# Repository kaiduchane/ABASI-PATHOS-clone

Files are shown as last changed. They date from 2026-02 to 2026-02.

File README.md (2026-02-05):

# ABASI-PATHOS-clone
The Abasi Pathos is a modern high-gain distortion pedal designed by guitarist Tosin Abasi and Horizon Devices. This project is an open-source clone that reverse-engineers the circuit for educational purposes and DIY builders.
This pedal features a three-band active EQ, dual-stage clipping circuit, and tight low-end response designed for modern progressive metal tones. The design uses through-hole components where possible to make it accessible for beginners while maintaining the sonic characteristics of the original.
Key Features:

Adjustable gain structure with asymmetrical clipping
Active 3-band EQ (Bass/Mid/Treble)
High input impedance JFET buffer
True bypass switching
Standard 9V center-negative power

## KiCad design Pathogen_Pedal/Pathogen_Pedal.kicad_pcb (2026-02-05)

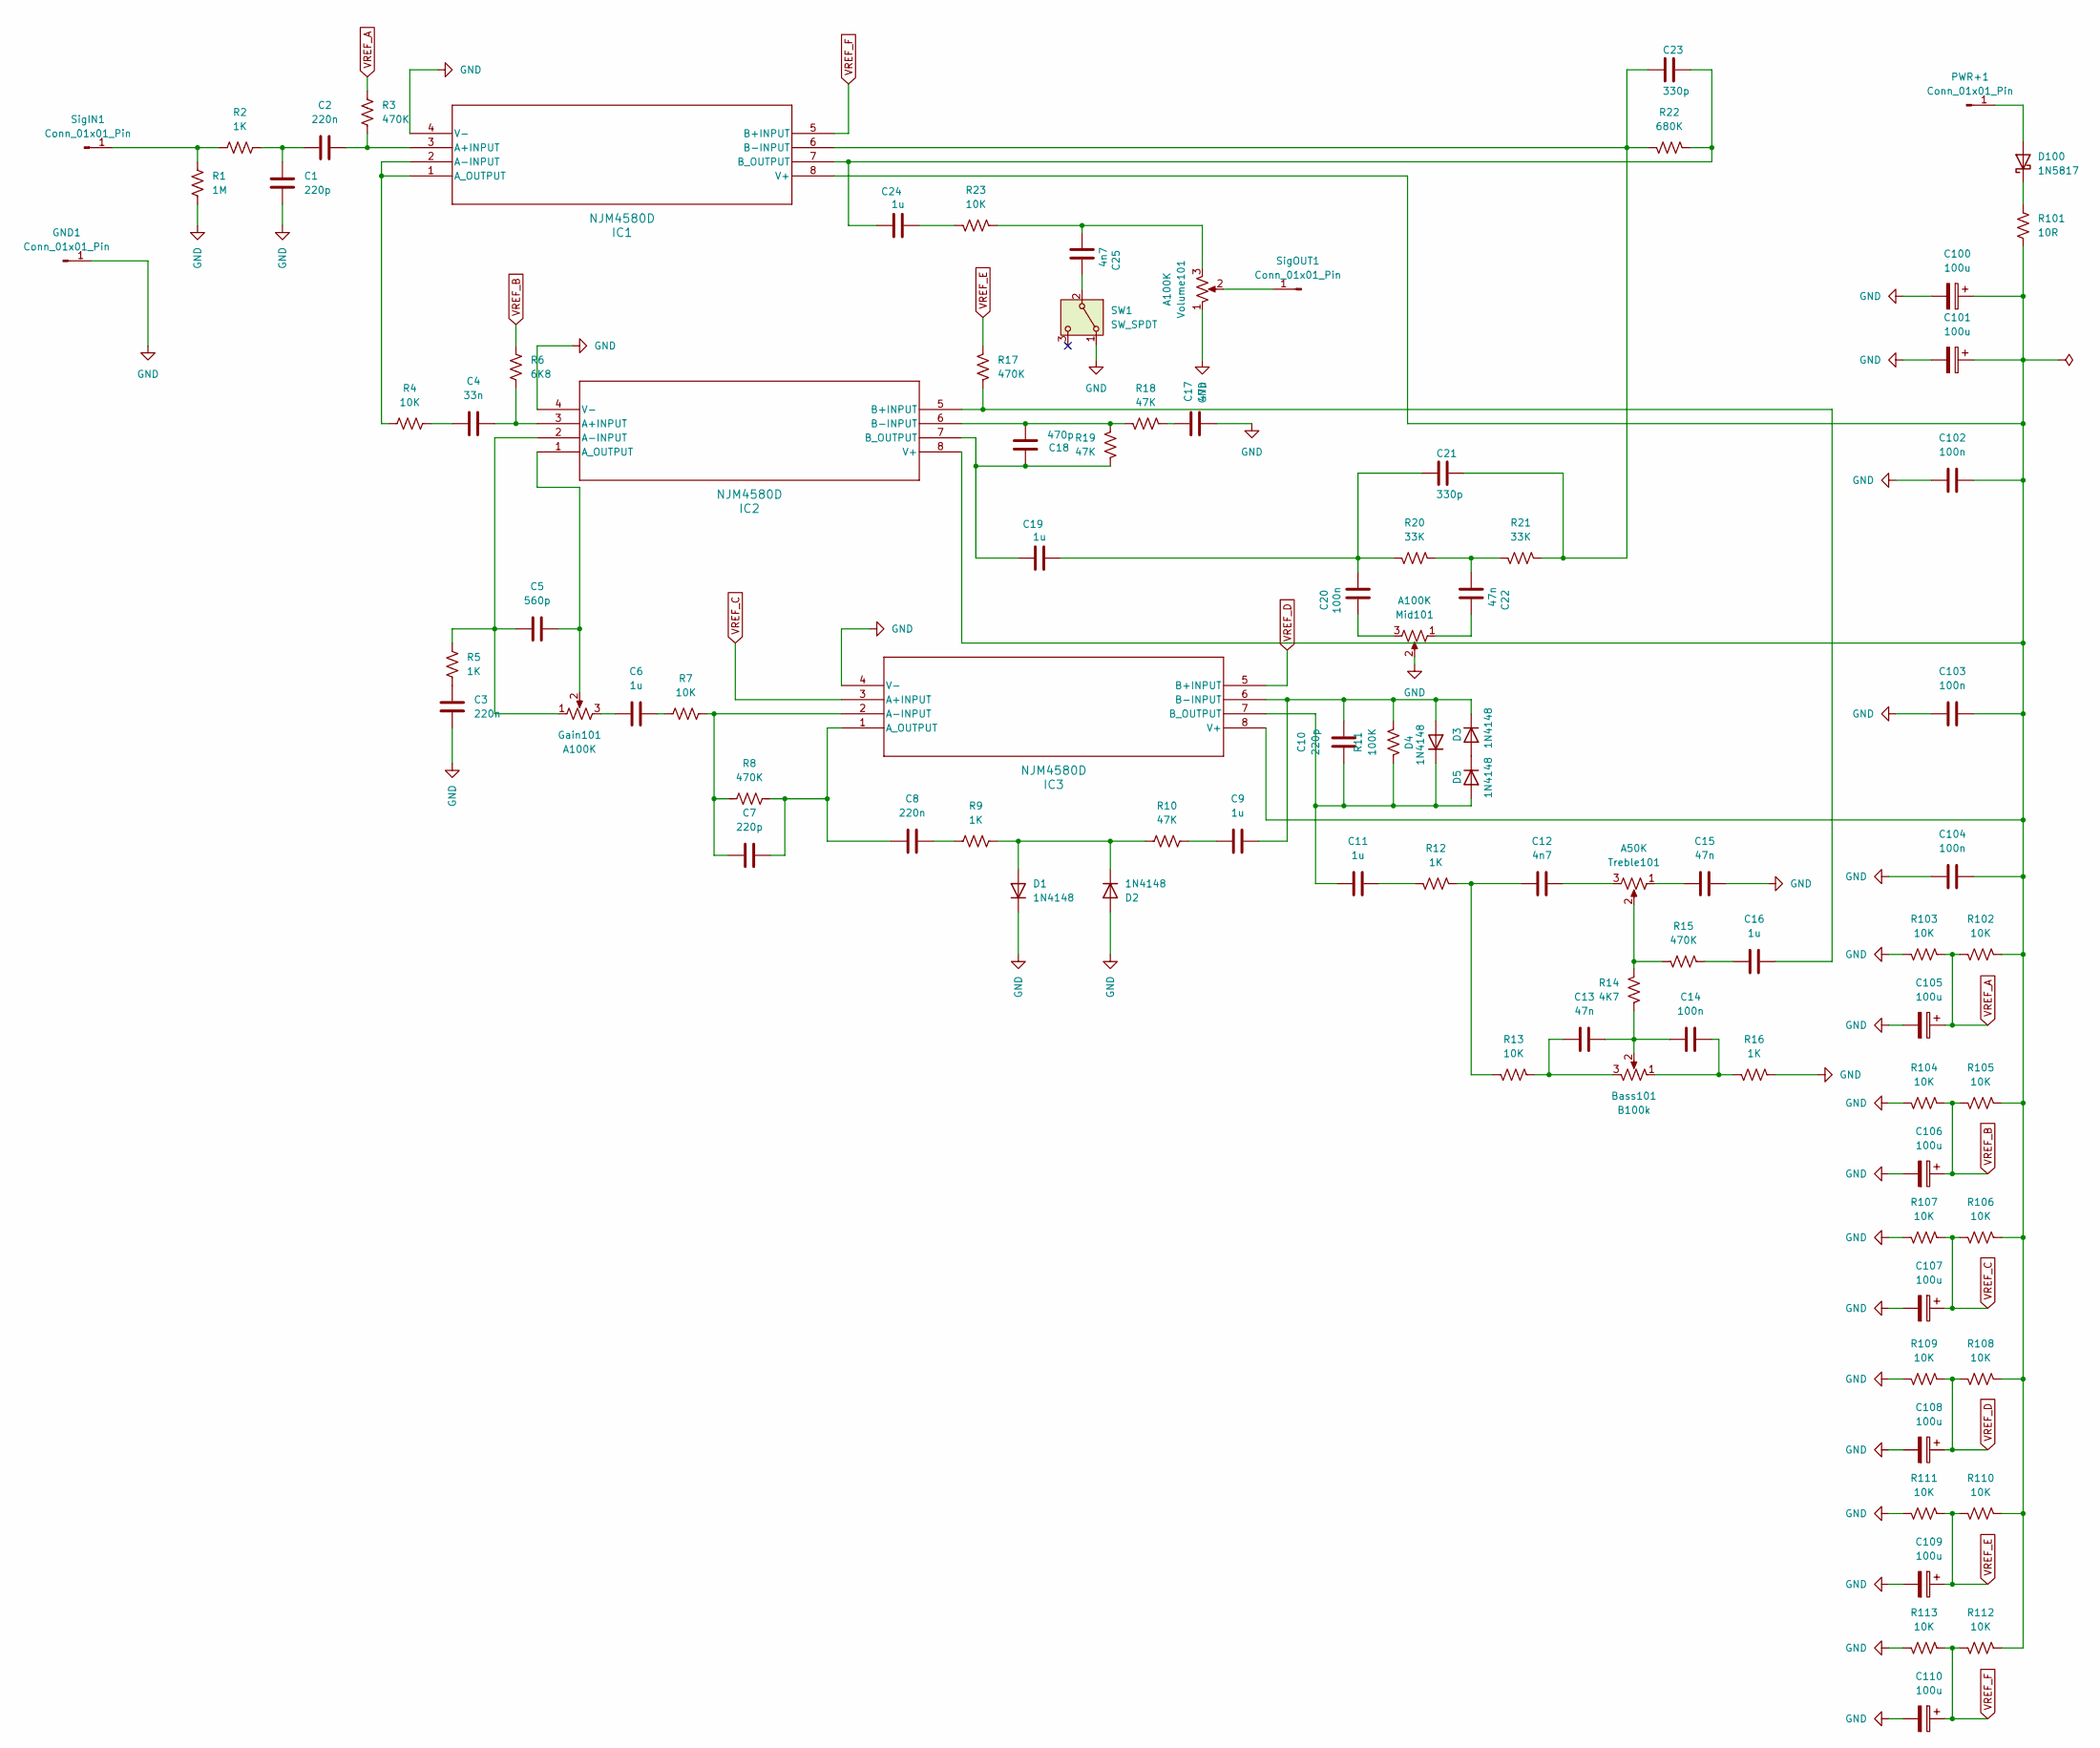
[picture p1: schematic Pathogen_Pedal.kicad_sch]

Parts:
Bass101: B100k; 16MM_PADS.2
C1, C7, C10: 220p; 5mm_10p-180n
C2, C3, C8: 220n; 5mm_1n-300n
C4: 33n; 7.62mm
C5: 560p; 7.62mm
C6, C9, C11, C16, C19, C24: 1u; C_Axial_L12.0mm_D6.5mm_P15.00mm_Horizontal
C12, C25: 4n7; 5mm_1n-300n
C13, C15, C17, C22: 47n; C_Axial_L17.0mm_D6.5mm_P20.00mm_Horizontal
C14, C20, C102, C103, C104: 100n; 5mm_1n-300n
C18: 470p; 5mm_10p-180n
C21, C23: 330p; 7.62mm
C100, C101, C105, C106, C107, C108, C109, C110: 100u; 0503
D1, D2, D3, D4, D5: 1N4148; DO41-2
D100: 1N5817; DO35-3
GND1: Conn_01x01_Pin; PAD3
Gain101: A100K; 16MM_PADS.2
IC1, IC2, IC3: NJM4580D; DIP08
Mid101: A100K; 16MM_PADS.2
PWR+1: Conn_01x01_Pin; PAD3
R1: 1M; 0.3%22.B
R2, R5, R9, R12, R16: 1K; 0.3%22.B
R3, R8, R15, R17: 470K; 0.3%22.B
R4, R7, R13, R23, R102, R103, R104, R105, R106, R107, R108, R109, R110, R111, R112, R113: 10K; 0.5%22
R6: 6K8; 0.3%22.B
R10, R18, R19: 47K; 0.3%22.B
R11: 100K; 0.2%22
R14: 4K7; 0.3%22.B
R20, R21: 33K; 0.4%22
R22: 680K; 0.3%22.B
R101: 10R; 0.3%22.B
SW1: SW_SPDT; SPDT.WIRE
SigIN1: Conn_01x01_Pin; PAD3
SigOUT1: Conn_01x01_Pin; PAD3
Treble101: A50K; 16MM_PADS.2
Volume101: A100K; 16MM_PADS.2

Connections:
GND: C1.2, C3.1, C15.2, C17.1, C100.2, C101.2, C102.1, C103.1, C104.1, C105.2, C106.2, C107.2, C108.2, C109.2, C110.2, D1.1 (K), D2.2 (A), GND1.1, IC1.4 (V-), IC2.4 (V-), IC3.4 (V-), Mid101.2, R1.1, R16.2, R103.1, R104.1, R107.1, R109.1, R111.1, R113.1, SW1.1 (A), Volume101.1
unnamed: Bass101.1, C14.2, R16.1
unnamed: Bass101.2, C13.2, C14.1, R14.1
unnamed: Bass101.3, C13.1, R13.2
unnamed: C1.1, C2.1, R2.1
unnamed: C3.2, R5.1
unnamed: C4.1, R4.2
unnamed: C6.1, R7.2
unnamed: C6.2, Gain101.3
unnamed: C8.1, R9.2
unnamed: C9.2, R10.1
unnamed: C11.2, R12.1
unnamed: C12.1, R12.2, R13.1
unnamed: C12.2, Treble101.3
unnamed: C15.1, Treble101.1
unnamed: C16.1, R15.1
unnamed: C17.2, R18.2
unnamed: C19.1, C20.1, C21.1, R20.1
unnamed: C20.2, Mid101.3
unnamed: C22.1, R20.2, R21.1
unnamed: C22.2, Mid101.1
unnamed: C24.1, R23.1
unnamed: C25.1, R23.2, Volume101.3
unnamed: D1.2 (A), D2.1 (K), R9.1, R10.2
unnamed: D3.2 (A), D5.1 (K)
unnamed: C9.1, C10.1, D3.1 (K), D4.2 (A), IC3.6 (B-INPUT), R11.1
unnamed: C10.2, C11.1, D4.1 (K), D5.2 (A), IC3.7 (B_OUTPUT), R11.2
unnamed 27: D100.2 (A), PWR+1.1; also elsewhere on the board
unnamed 28: D100.1 (K), R101.2; also elsewhere on the board
unnamed: C2.2, IC1.3 (A+INPUT), R3.2
unnamed: IC1.1 (A_OUTPUT), IC1.2 (A-INPUT), R4.1
unnamed: C21.2, C23.1, IC1.6 (B-INPUT), R21.2, R22.1
unnamed: C23.2, C24.2, IC1.7 (B_OUTPUT), R22.2
unnamed: C100.1, C101.1, C102.2, C103.2, C104.2, IC1.8 (V+), IC2.8 (V+), IC3.8 (V+), R101.1, R102.2, R105.2, R106.2, R108.2, R110.2, R112.2
unnamed: C4.2, IC2.3 (A+INPUT), R6.1
unnamed: C5.2, Gain101.1, IC2.2 (A-INPUT), R5.2
unnamed: C5.1, Gain101.2, IC2.1 (A_OUTPUT)
unnamed: C16.2, IC2.5 (B+INPUT), R17.2
unnamed: C18.2, IC2.6 (B-INPUT), R18.1, R19.2
unnamed: C18.1, C19.2, IC2.7 (B_OUTPUT), R19.1
unnamed: C7.2, IC3.2 (A-INPUT), R7.1, R8.2
unnamed: C7.1, C8.2, IC3.1 (A_OUTPUT), R8.1
unnamed: R14.2, R15.2, Treble101.2
unnamed: C25.2, SW1.2 (B)
unnamed: R1.2, R2.2, SigIN1.1
unnamed: SigOUT1.1, Volume101.2
VREF_A: C105.1, R3.1, R102.1, R103.2
VREF_B: C106.1, R6.2, R104.2, R105.1
VREF_C: C107.1, IC3.3 (A+INPUT), R106.1, R107.2
VREF_D: C108.1, IC3.5 (B+INPUT), R108.1, R109.2
VREF_E: C109.1, R17.1, R110.1, R111.2
VREF_F: C110.1, IC1.5 (B+INPUT), R112.1, R113.2

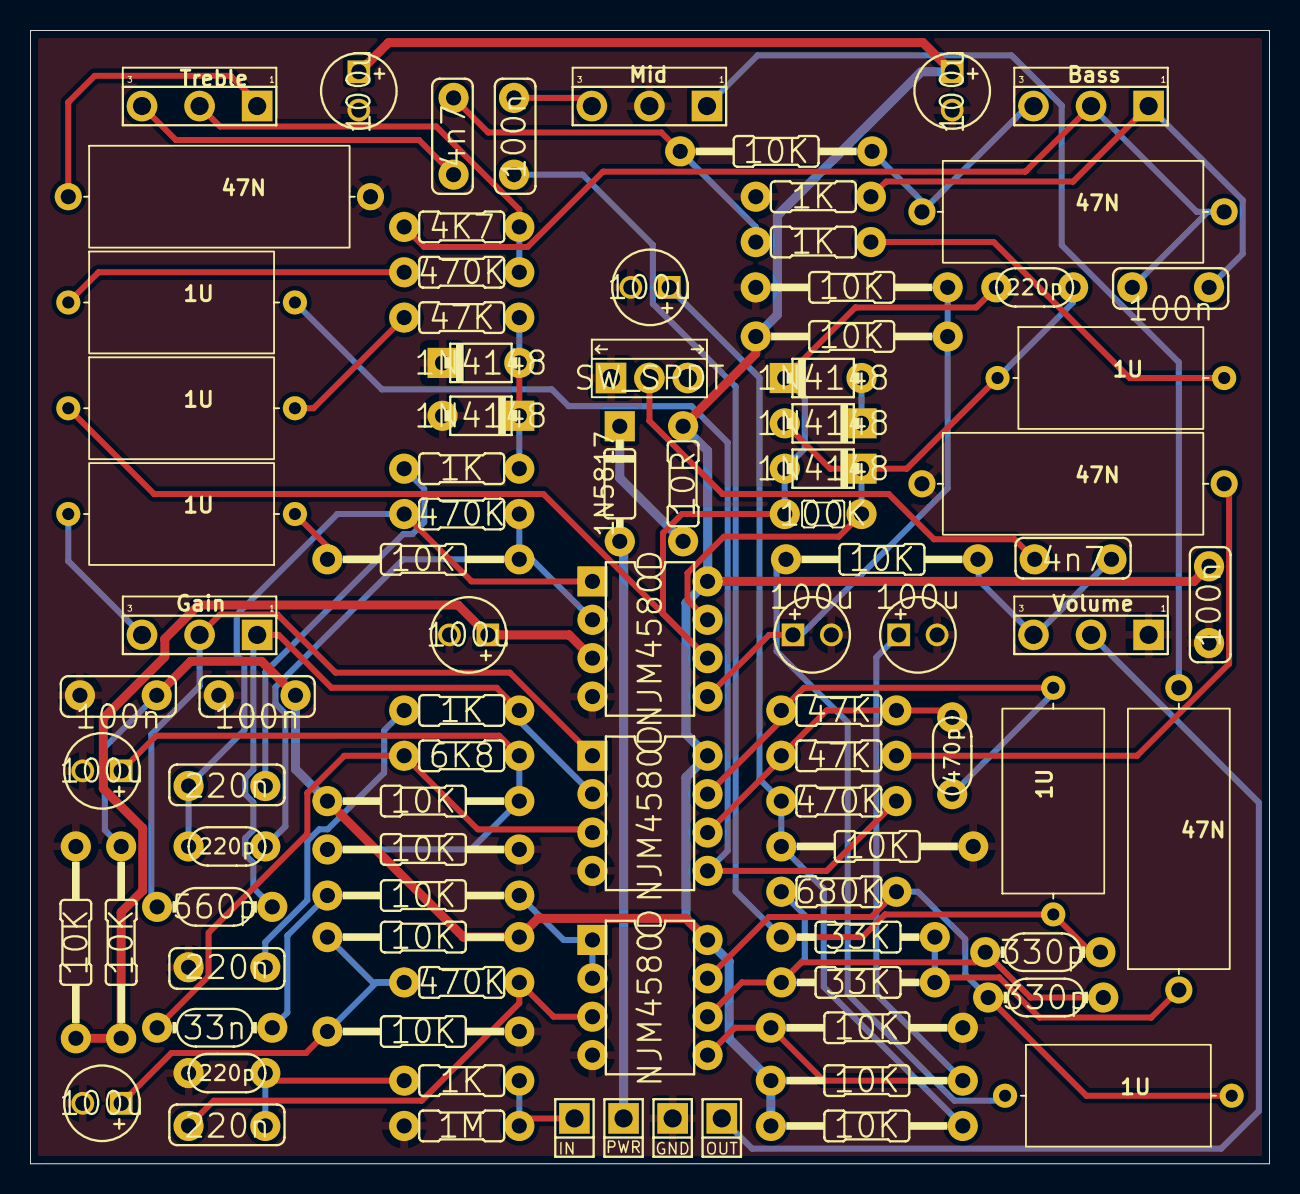
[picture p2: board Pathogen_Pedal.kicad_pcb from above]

Board: 4 copper layers, 82.0 x 75.0 mm, 91 parts (0 on the bottom side), 52 nets.

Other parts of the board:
1N5817: 1N5817; DO35-3

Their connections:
unnamed 27: 1N5817.2 (A); also elsewhere on the board
unnamed 28: 1N5817.1 (K); also elsewhere on the board

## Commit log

2026-02-05 Pathos Folder
    [Pathogen_Pedal.kicad_pcb, Pathogen_Pedal.kicad_sch]
2026-02-05 Gerber files for JLC PCB
    [Pathogen_Pedal-B_Mask.gbs, Pathogen_Pedal-B_Paste.gbp, Pathogen_Pedal-B_Silkscreen.gbo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]
